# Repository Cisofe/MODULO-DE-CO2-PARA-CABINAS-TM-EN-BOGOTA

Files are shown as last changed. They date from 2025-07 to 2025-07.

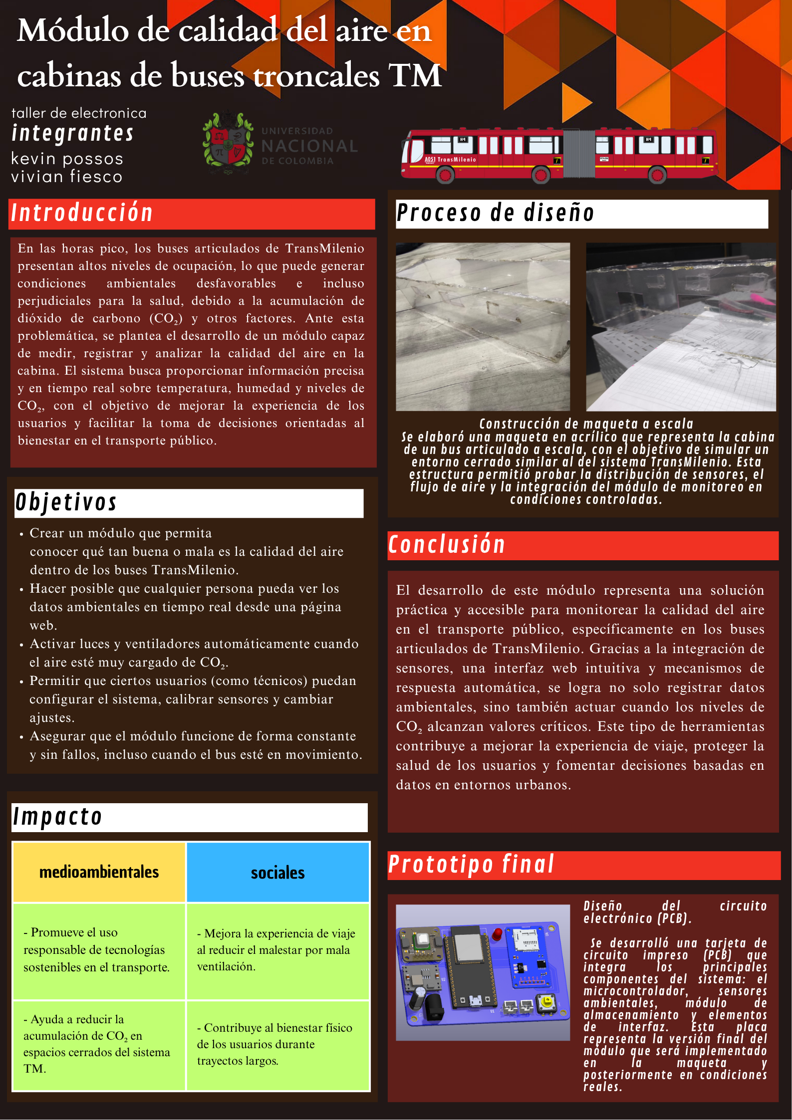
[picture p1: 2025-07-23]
Evidencias/poster.png.png

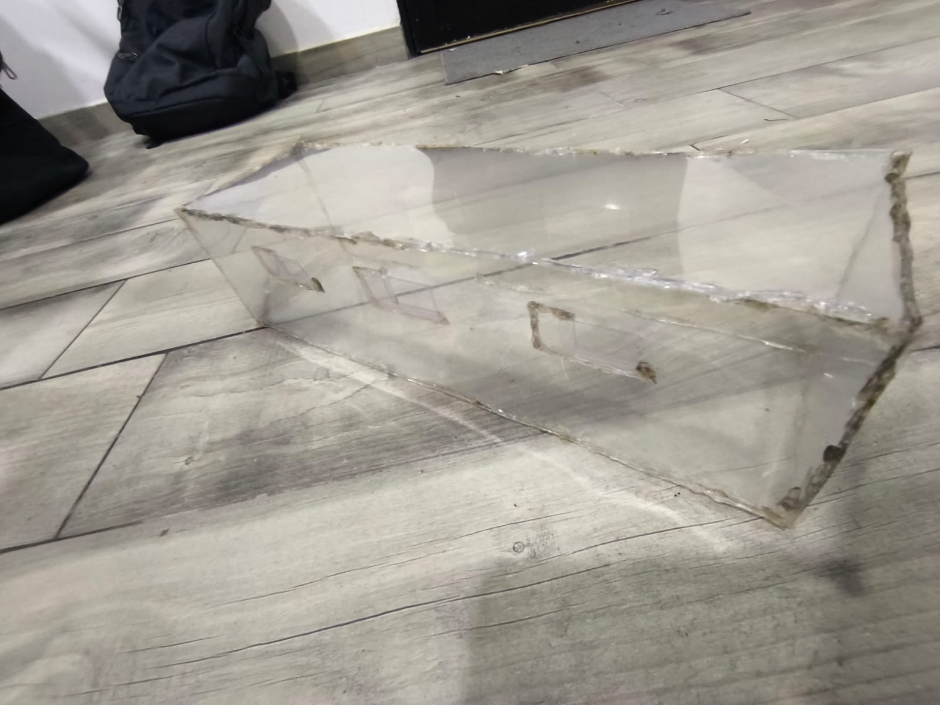
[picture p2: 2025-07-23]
Evidencias/Evidencia_cabina_escala.jpg

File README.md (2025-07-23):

# MODULO-DE-CO2-PARA-CABINAS-TM-EN-BOGOTA
## Proyecto de ingeniería

El módulo de CO2 para buses TM es un prototipo ideado para proporcionar datos para análisis y control de la calidad del aire en las cabinas de buses troncales del sistema BRT de la ciudad de Bogotá, Colombia. El dispositivo permite que los estadísticos y analistas de datos obtengan información de la temperatura, humedad y concentración de CO2 en el interior de los vehículos, además de automatizar el funcionamiento del sistema de ventilación de acuerdo a los valores de concentración de CO2. Las personas que conmutan a diario en los buses también podrán acceder a datos recientes de la calidad del aire en su cabina, lo que busca proporcionar más transparencia y aumentar el interés de los usuarios en el tema. Asimismo, esto podría incidir en el incremento de estudios sobre la aglomeración de TransMilenio y las condiciones del aire en sistemas de transporte masivo público y cómo influyen en el pasajero.

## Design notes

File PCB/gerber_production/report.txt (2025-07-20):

Plotted to 'C:\Users\vivi_\Módulo de CO2 de buses TM\Modulo CO2 de bus TM\gerber_production\Modulo CO2 de bus TM-F_Cu.gbr'.
Plotted to 'C:\Users\vivi_\Módulo de CO2 de buses TM\Modulo CO2 de bus TM\gerber_production\Modulo CO2 de bus TM-B_Cu.gbr'.
Plotted to 'C:\Users\vivi_\Módulo de CO2 de buses TM\Modulo CO2 de bus TM\gerber_production\Modulo CO2 de bus TM-B_Paste.gbr'.
Plotted to 'C:\Users\vivi_\Módulo de CO2 de buses TM\Modulo CO2 de bus TM\gerber_production\Modulo CO2 de bus TM-F_Silkscreen.gbr'.
Plotted to 'C:\Users\vivi_\Módulo de CO2 de buses TM\Modulo CO2 de bus TM\gerber_production\Modulo CO2 de bus TM-B_Silkscreen.gbr'.
Plotted to 'C:\Users\vivi_\Módulo de CO2 de buses TM\Modulo CO2 de bus TM\gerber_production\Modulo CO2 de bus TM-F_Mask.gbr'.
Plotted to 'C:\Users\vivi_\Módulo de CO2 de buses TM\Modulo CO2 de bus TM\gerber_production\Modulo CO2 de bus TM-B_Mask.gbr'.
Plotted to 'C:\Users\vivi_\Módulo de CO2 de buses TM\Modulo CO2 de bus TM\gerber_production\Modulo CO2 de bus TM-Edge_Cuts.gbr'.
Created Gerber job file 'C:\Users\vivi_\Módulo de CO2 de buses TM\Modulo CO2 de bus TM\gerber_production\Modulo CO2 de bus TM-job.gbrjob'.
Info: Done.

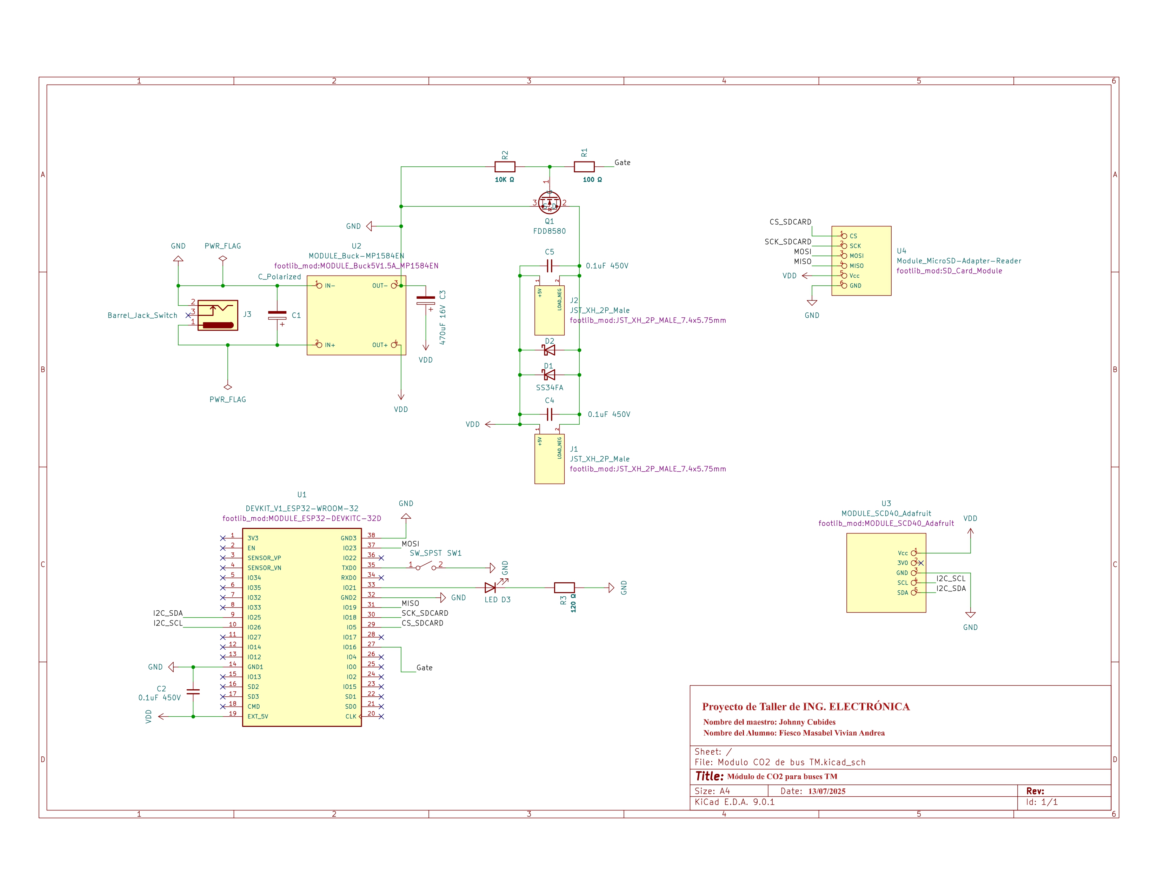
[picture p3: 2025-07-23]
PCB/Schematic_Modulo_CO2_de_bus_TM.jpg

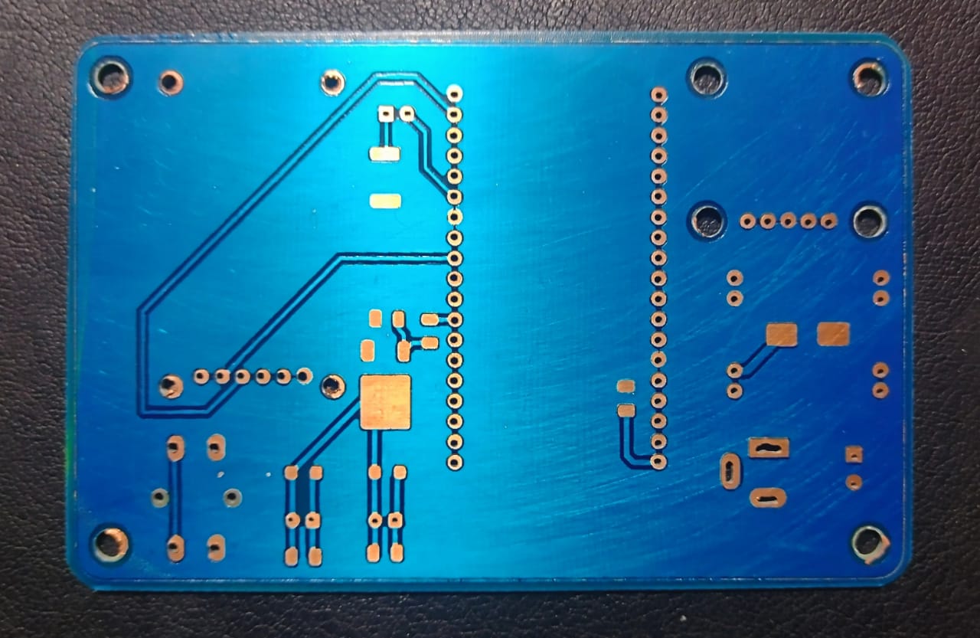
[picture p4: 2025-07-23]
Evidencias/pcb_layout_Back.jpeg

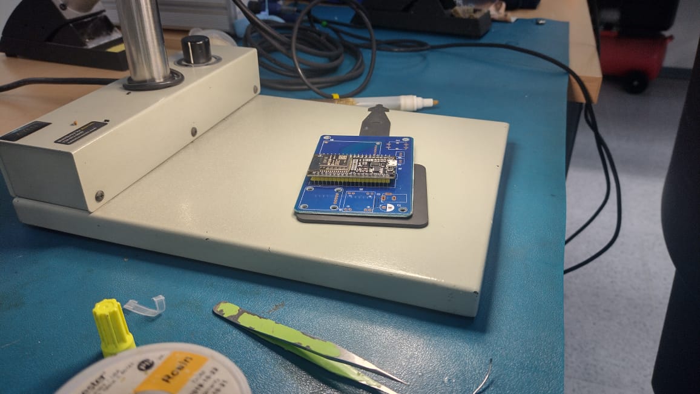
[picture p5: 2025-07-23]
Evidencias/Evidencia_soldadura1.jpeg

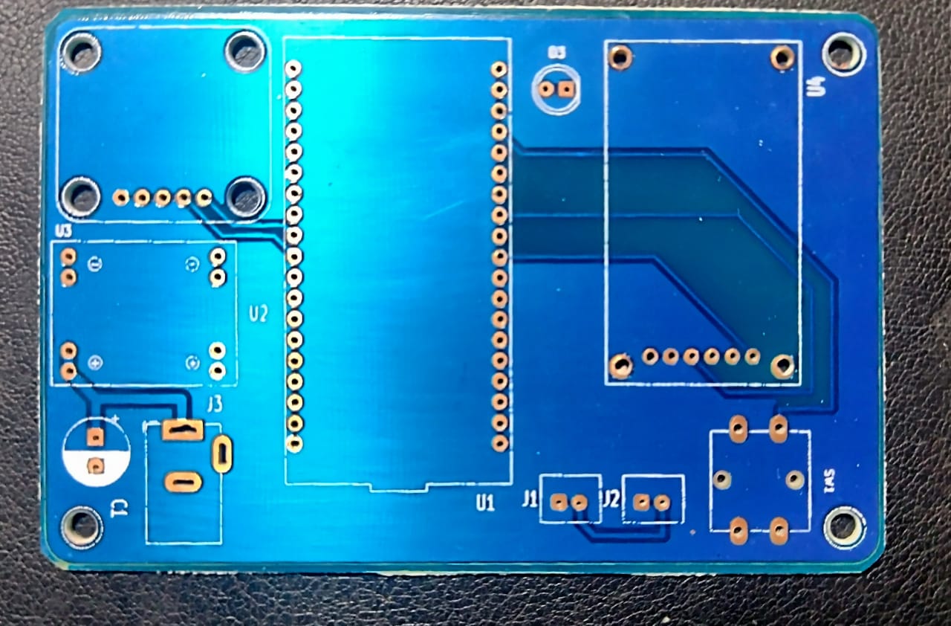
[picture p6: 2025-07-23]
Evidencias/pcb_layout_Front.jpeg

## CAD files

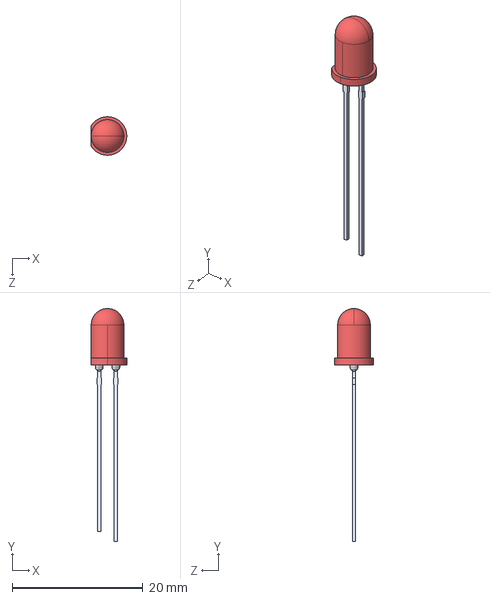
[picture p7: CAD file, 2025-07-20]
PCB/3d-models/LED_5mm.STEP
5.45 x 35.6 x 5.90 mm

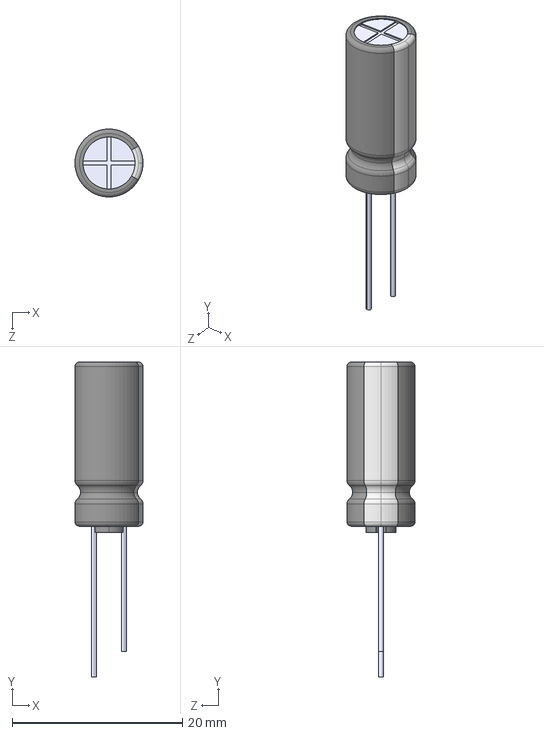
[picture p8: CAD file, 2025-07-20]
PCB/3d-models/CAP_8mm 3.5mm.STEP
8.00 x 37.0 x 7.99 mm

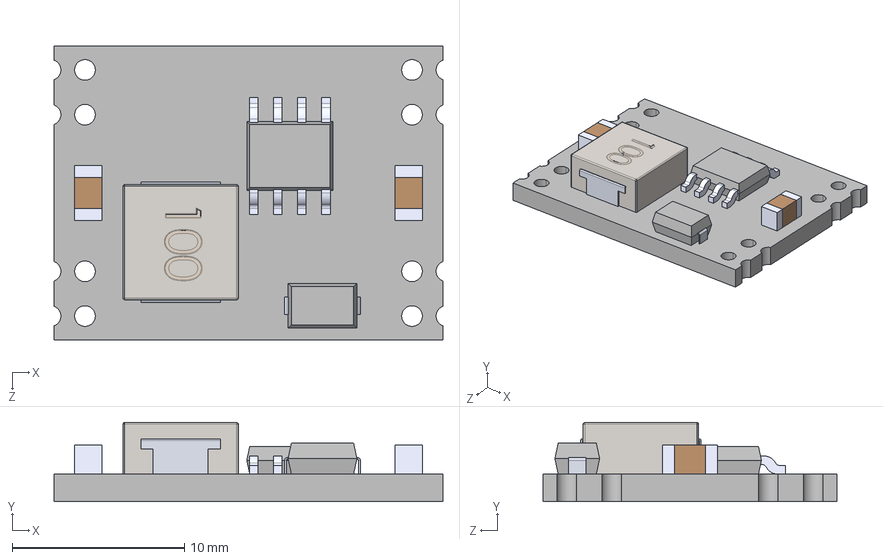
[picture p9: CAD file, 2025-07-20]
PCB/3d-models/DC-DC 5V-12V To 3.3V Step Down Voltage Regulator Power Module Board.STEP
22.6 x 4.60 x 17.1 mm
PCB, DC-DC 5V-12V To 3.3V Step Down Voltage Regulator Power Module Board
IC Chip, DC-DC 5V-12V To 3.3V Step Down Voltage Regulator Power Module Board
Inductor, DC-DC 5V-12V To 3.3V Step Down Voltage Regulator Power Module Board
Schottky Diode, DC-DC 5V-12V To 3.3V Step Down Voltage Regulator Power Module Board
SMD Resistor, DC-DC 5V-12V To 3.3V Step Down Voltage Regulator Power Module Board x 2

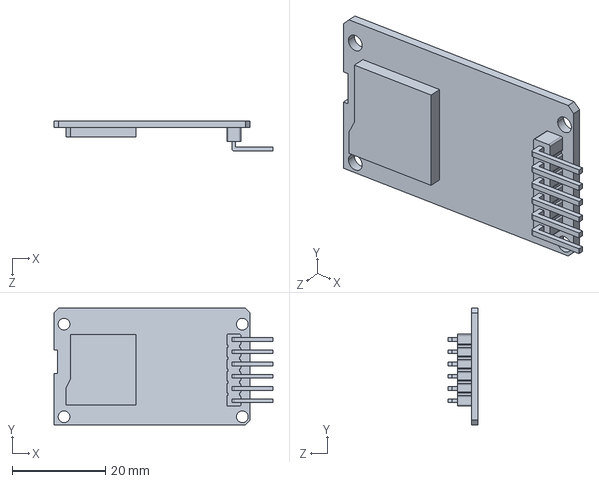
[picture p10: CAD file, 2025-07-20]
PCB/3d-models/sdreader.STEP
46.9 x 25.0 x 6.40 mm

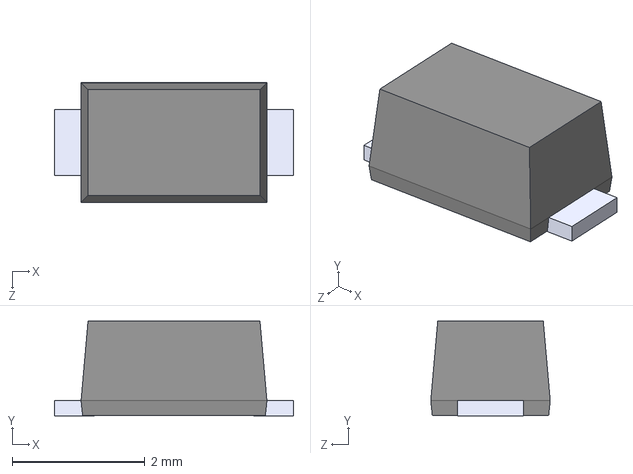
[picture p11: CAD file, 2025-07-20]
PCB/3d-models/SS34FA--3DModel-STEP-510211.STEP
3.60 x 1.43 x 1.80 mm

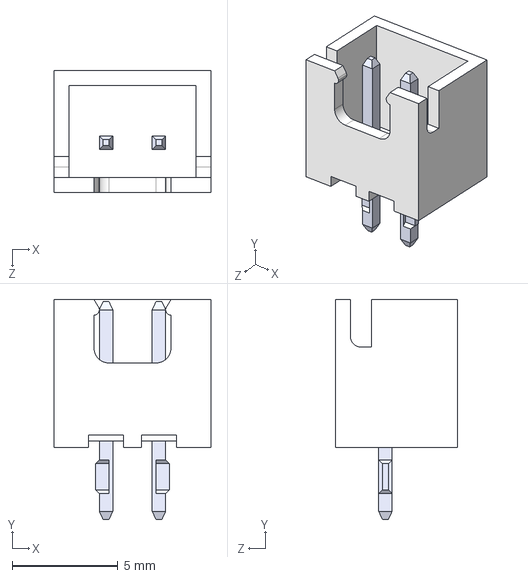
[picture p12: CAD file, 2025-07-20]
PCB/3d-models/B2B-XH-A-LF--SN---3DModel-STEP-269445.STEP
7.40 x 10.4 x 5.75 mm

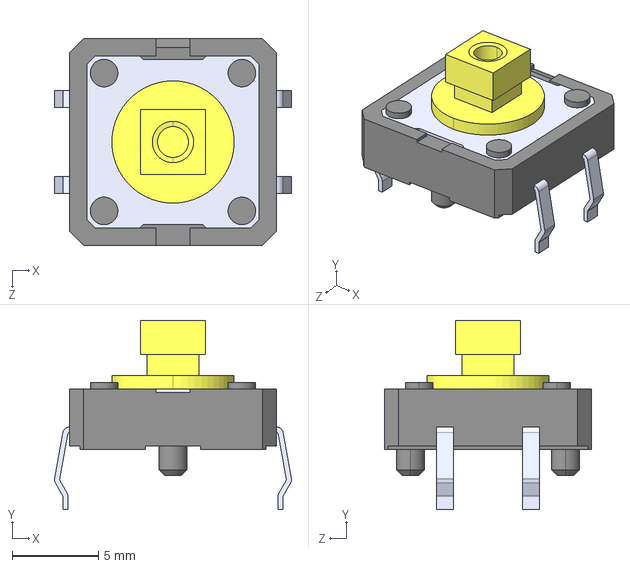
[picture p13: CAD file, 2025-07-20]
PCB/3d-models/B3F-4055--3DModel-STEP-418109.STEP
13.8 x 11.0 x 12.0 mm

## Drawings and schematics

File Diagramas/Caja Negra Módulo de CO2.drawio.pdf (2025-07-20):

## Aire

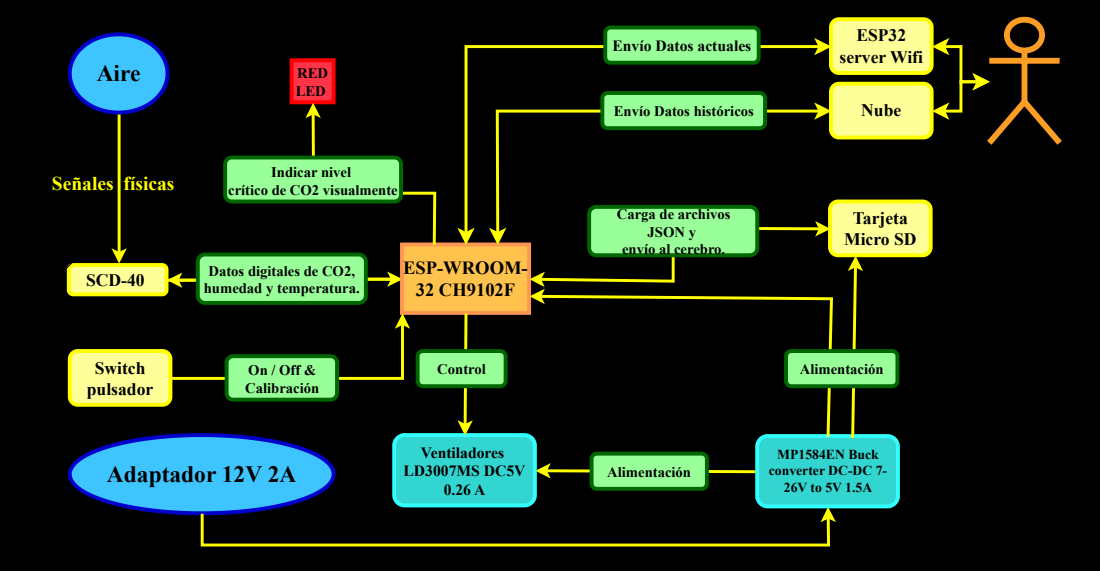
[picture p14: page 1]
SCD-40; Señales; físicas; ESP-WROOM- 32 CH9102F; Adaptador 12V 2A; Tarjeta Micro SD; Actor; Nube; ESP32 server Wifi; Alimentación; Ventiladores LD3007MS DC5V 0.26 A; Control; RED LED; Switch pulsador; On / Off & Calibración

Envío Datos actuales

Envío Datos históricos

Indicar nivel
crítico de CO2 visualmente

Carga de archivos
JSON y
envío al cerebro.

Datos digitales de CO2,
humedad y temperatura.

MP1584EN Buck
converter DC-DC 7-

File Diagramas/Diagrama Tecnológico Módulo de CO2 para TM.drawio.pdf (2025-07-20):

## Aire

## Señales físicas

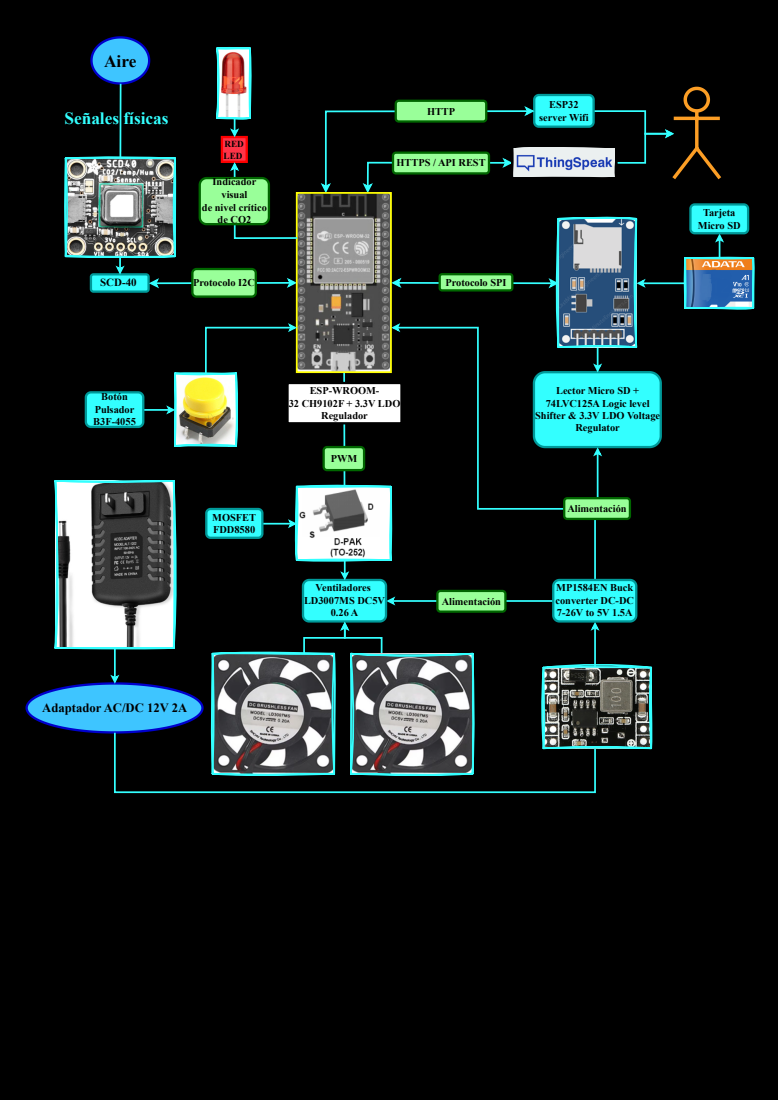
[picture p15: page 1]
SCD-40; Regulator; Actor; ESP32 server Wifi; Alimentación; HTTP; Ventiladores LD3007MS DC5V 0.26 A; MOSFET FDD8580; RED LED; Protocolo I2C; ESP-WROOM- 32 CH9102F + 3.3V LDO Regulador; Protocolo SPI; Tarjeta Micro SD; Botón Pulsador B3F-4055; PWM

HTTPS / API REST

Indicador
visual
de nivel crítico

Lector Micro SD +
74LVC125A Logic level
Shifter & 3.3V LDO Voltage

MP1584EN Buck
converter DC-DC

Adaptador AC/DC 12V 2A

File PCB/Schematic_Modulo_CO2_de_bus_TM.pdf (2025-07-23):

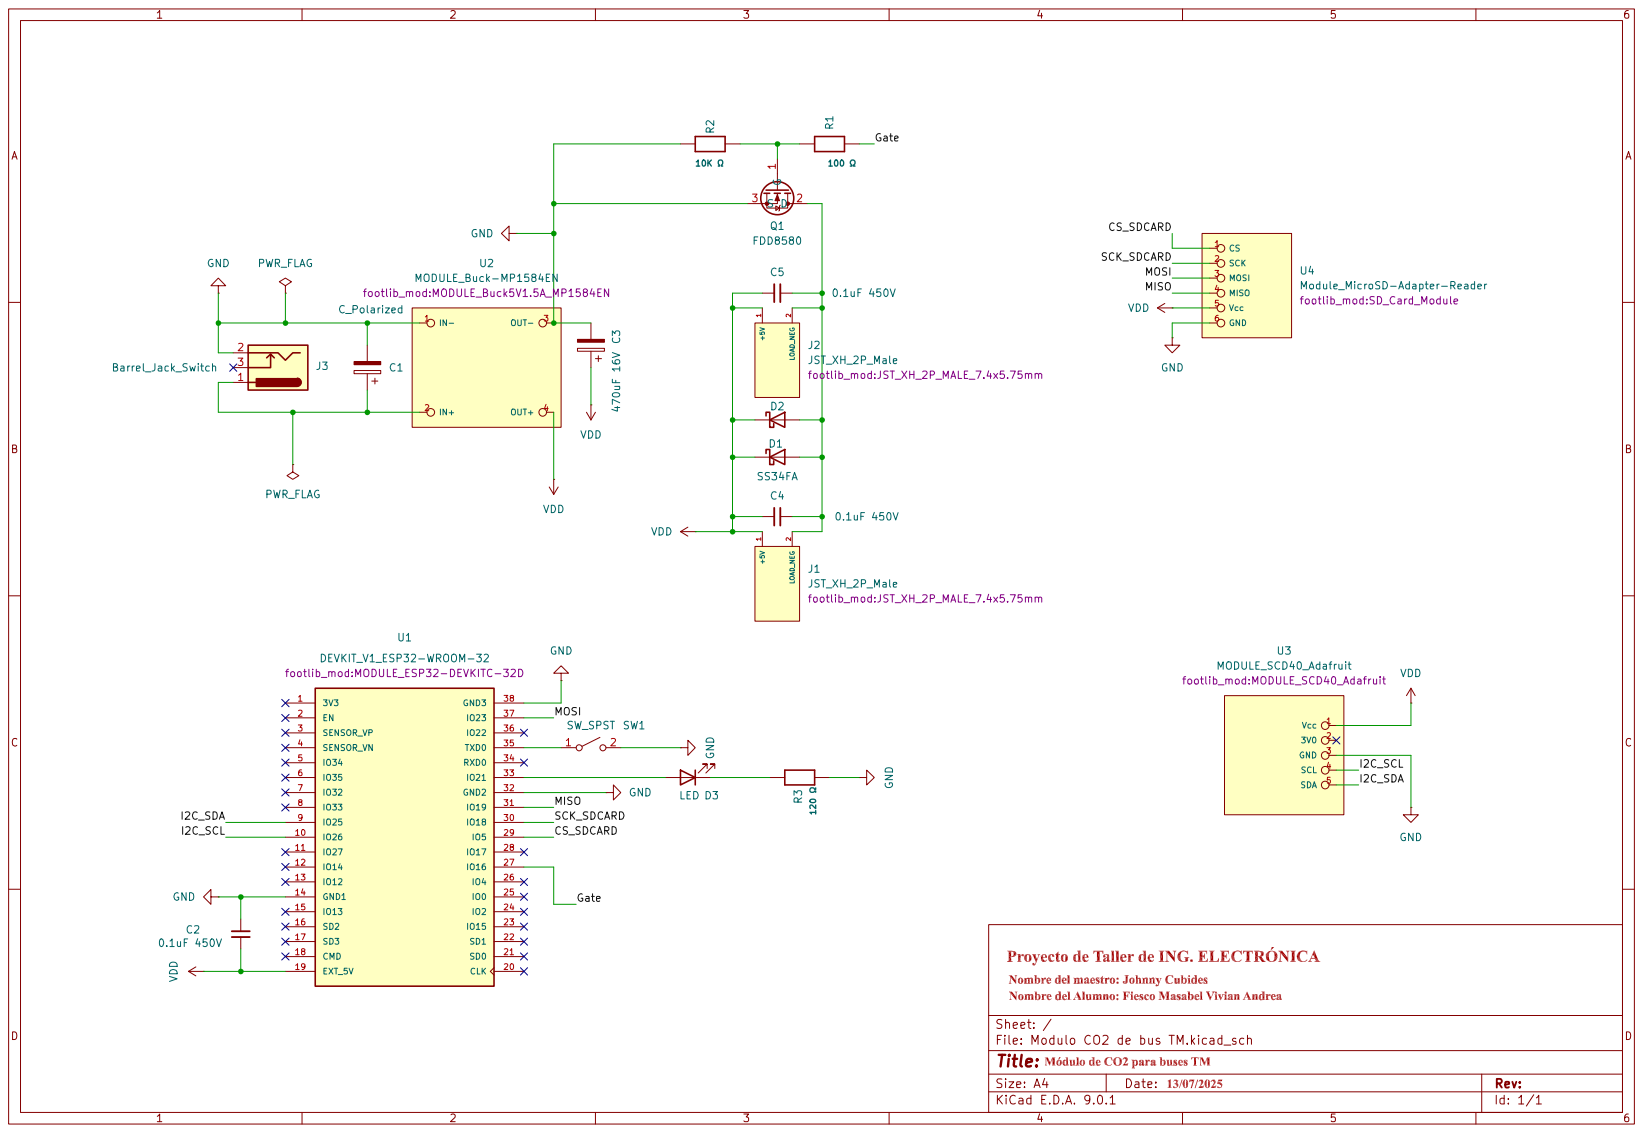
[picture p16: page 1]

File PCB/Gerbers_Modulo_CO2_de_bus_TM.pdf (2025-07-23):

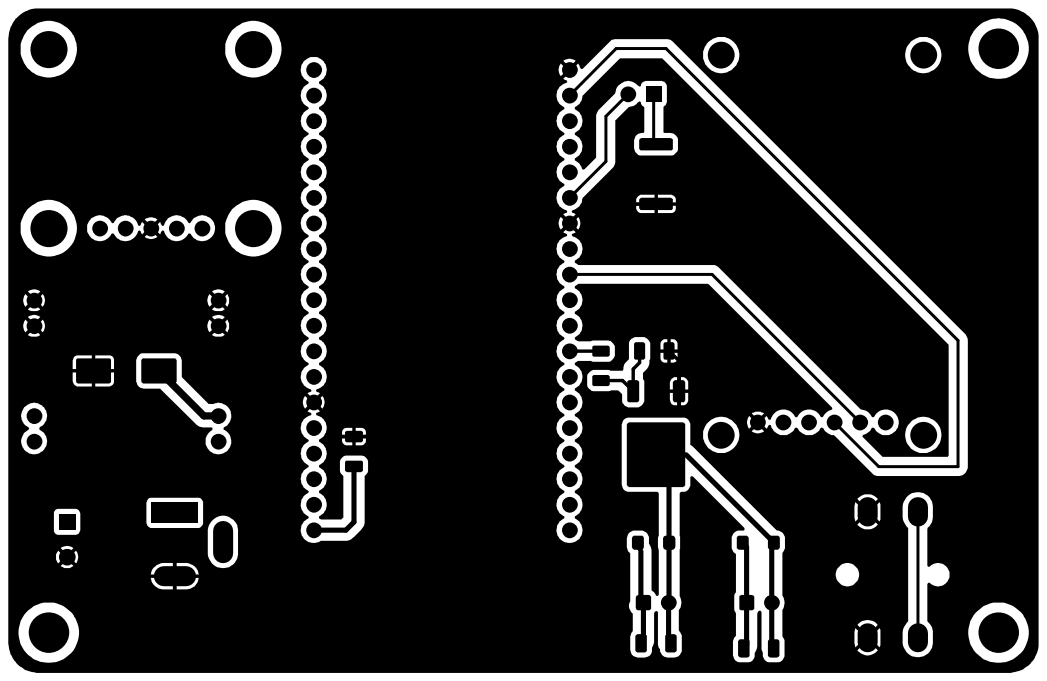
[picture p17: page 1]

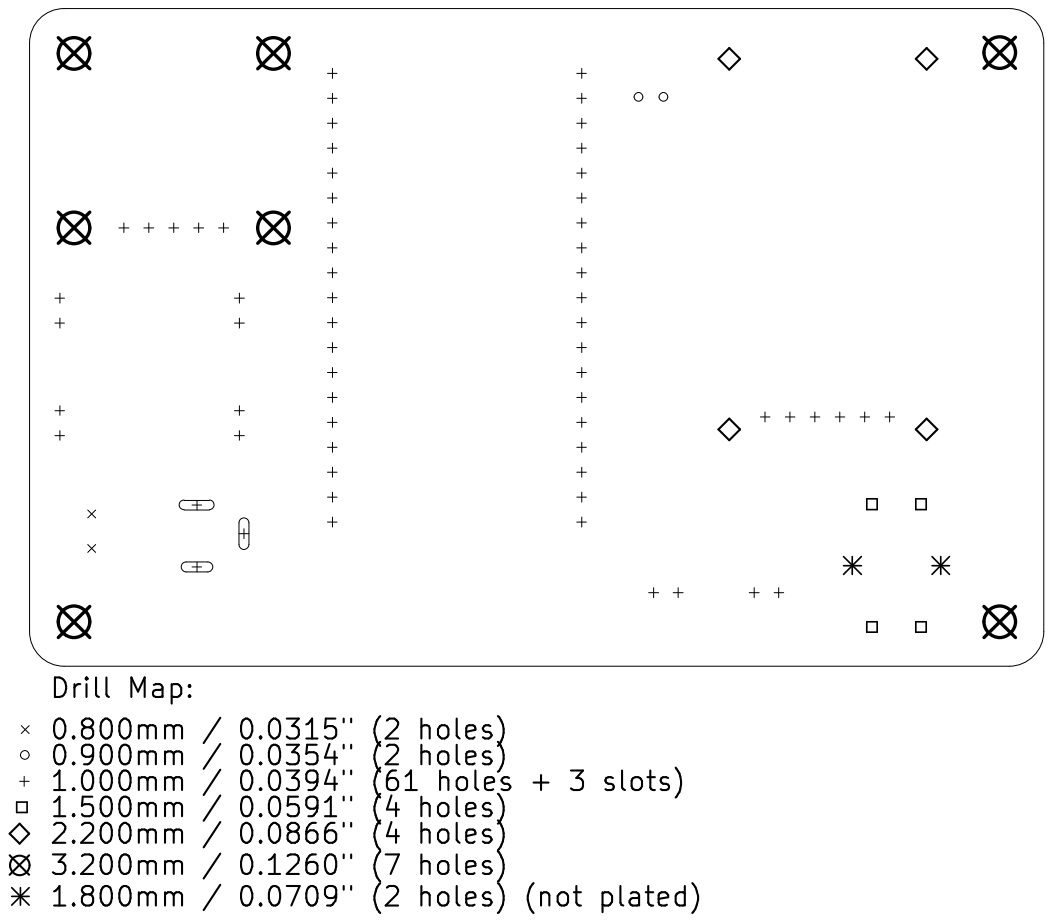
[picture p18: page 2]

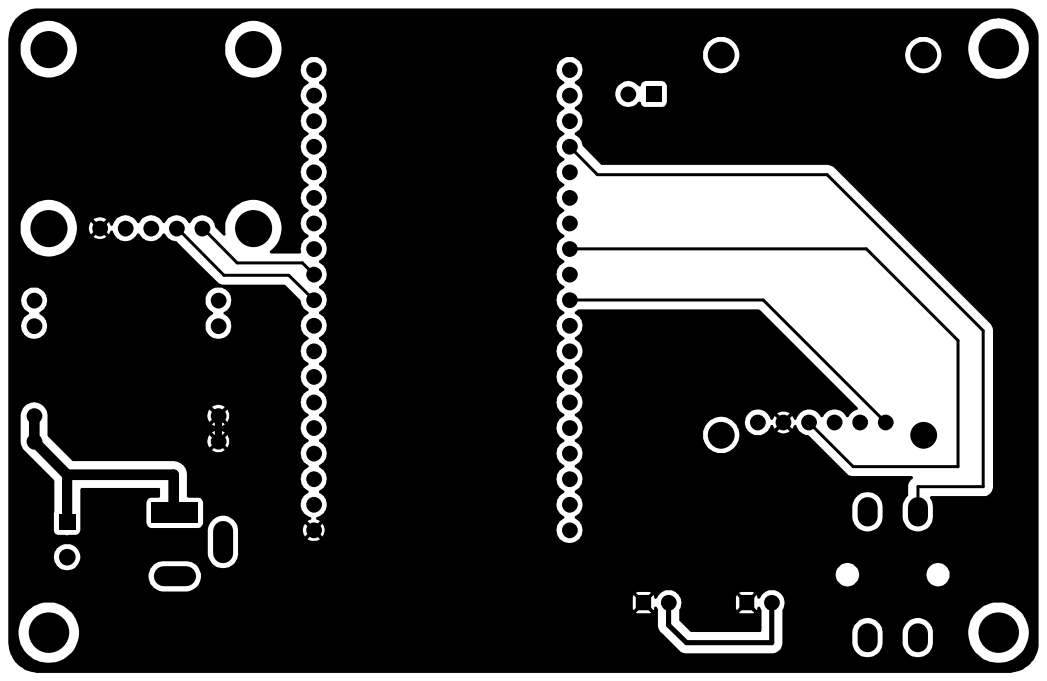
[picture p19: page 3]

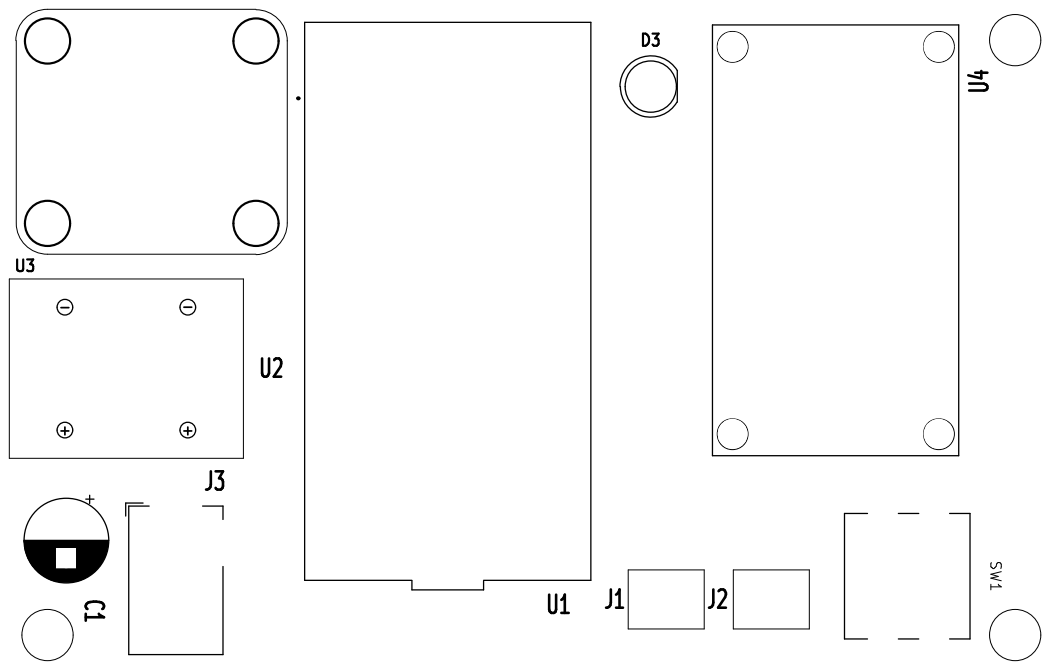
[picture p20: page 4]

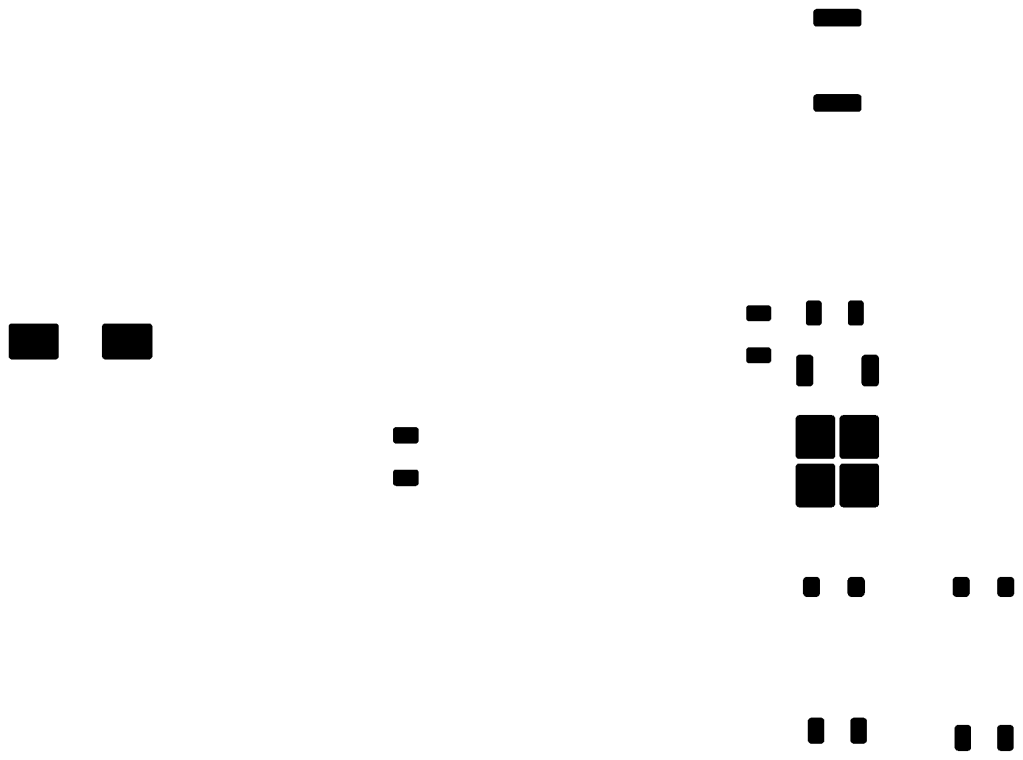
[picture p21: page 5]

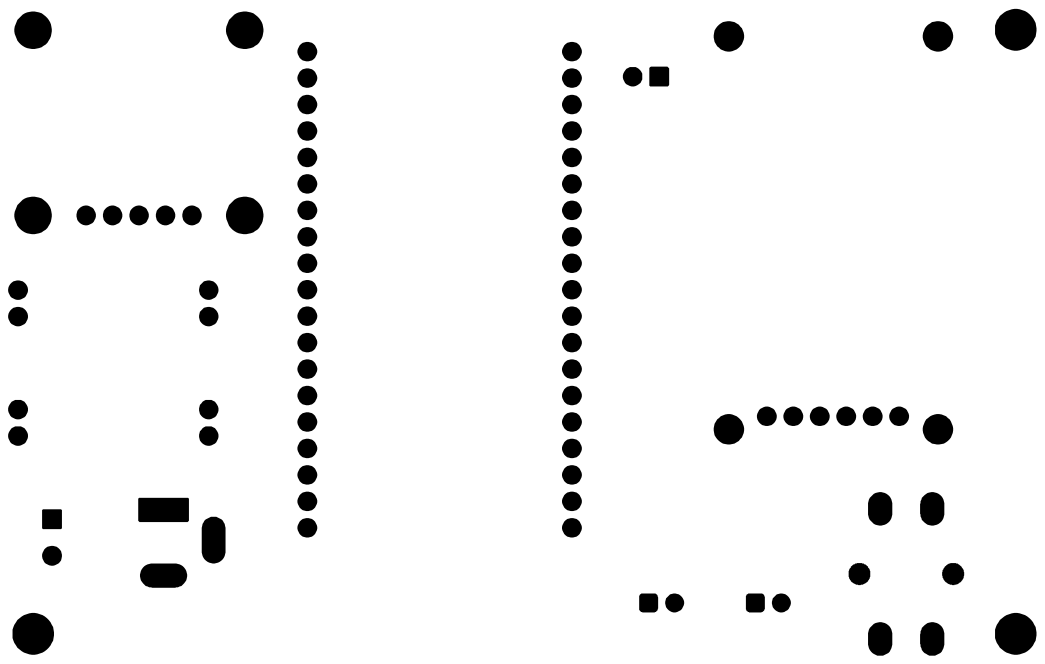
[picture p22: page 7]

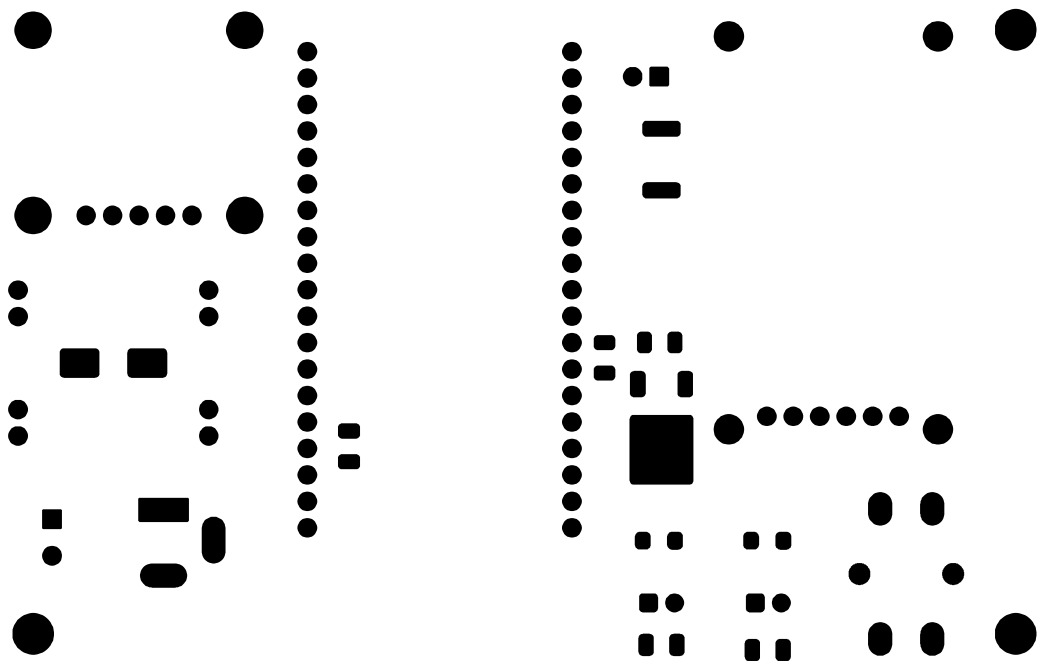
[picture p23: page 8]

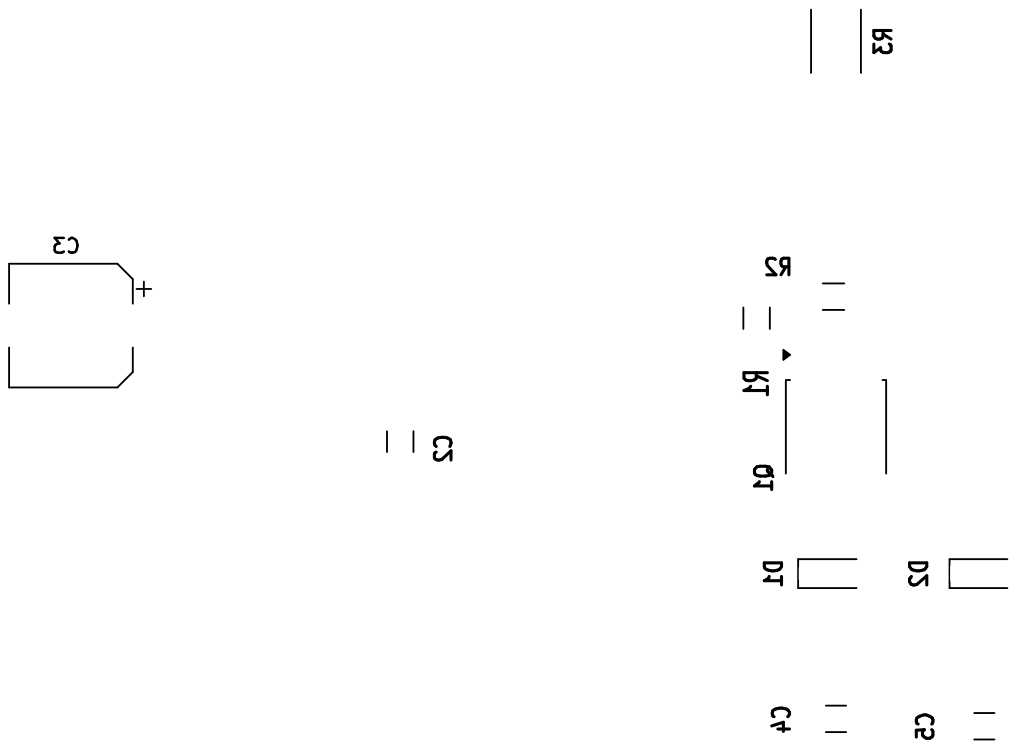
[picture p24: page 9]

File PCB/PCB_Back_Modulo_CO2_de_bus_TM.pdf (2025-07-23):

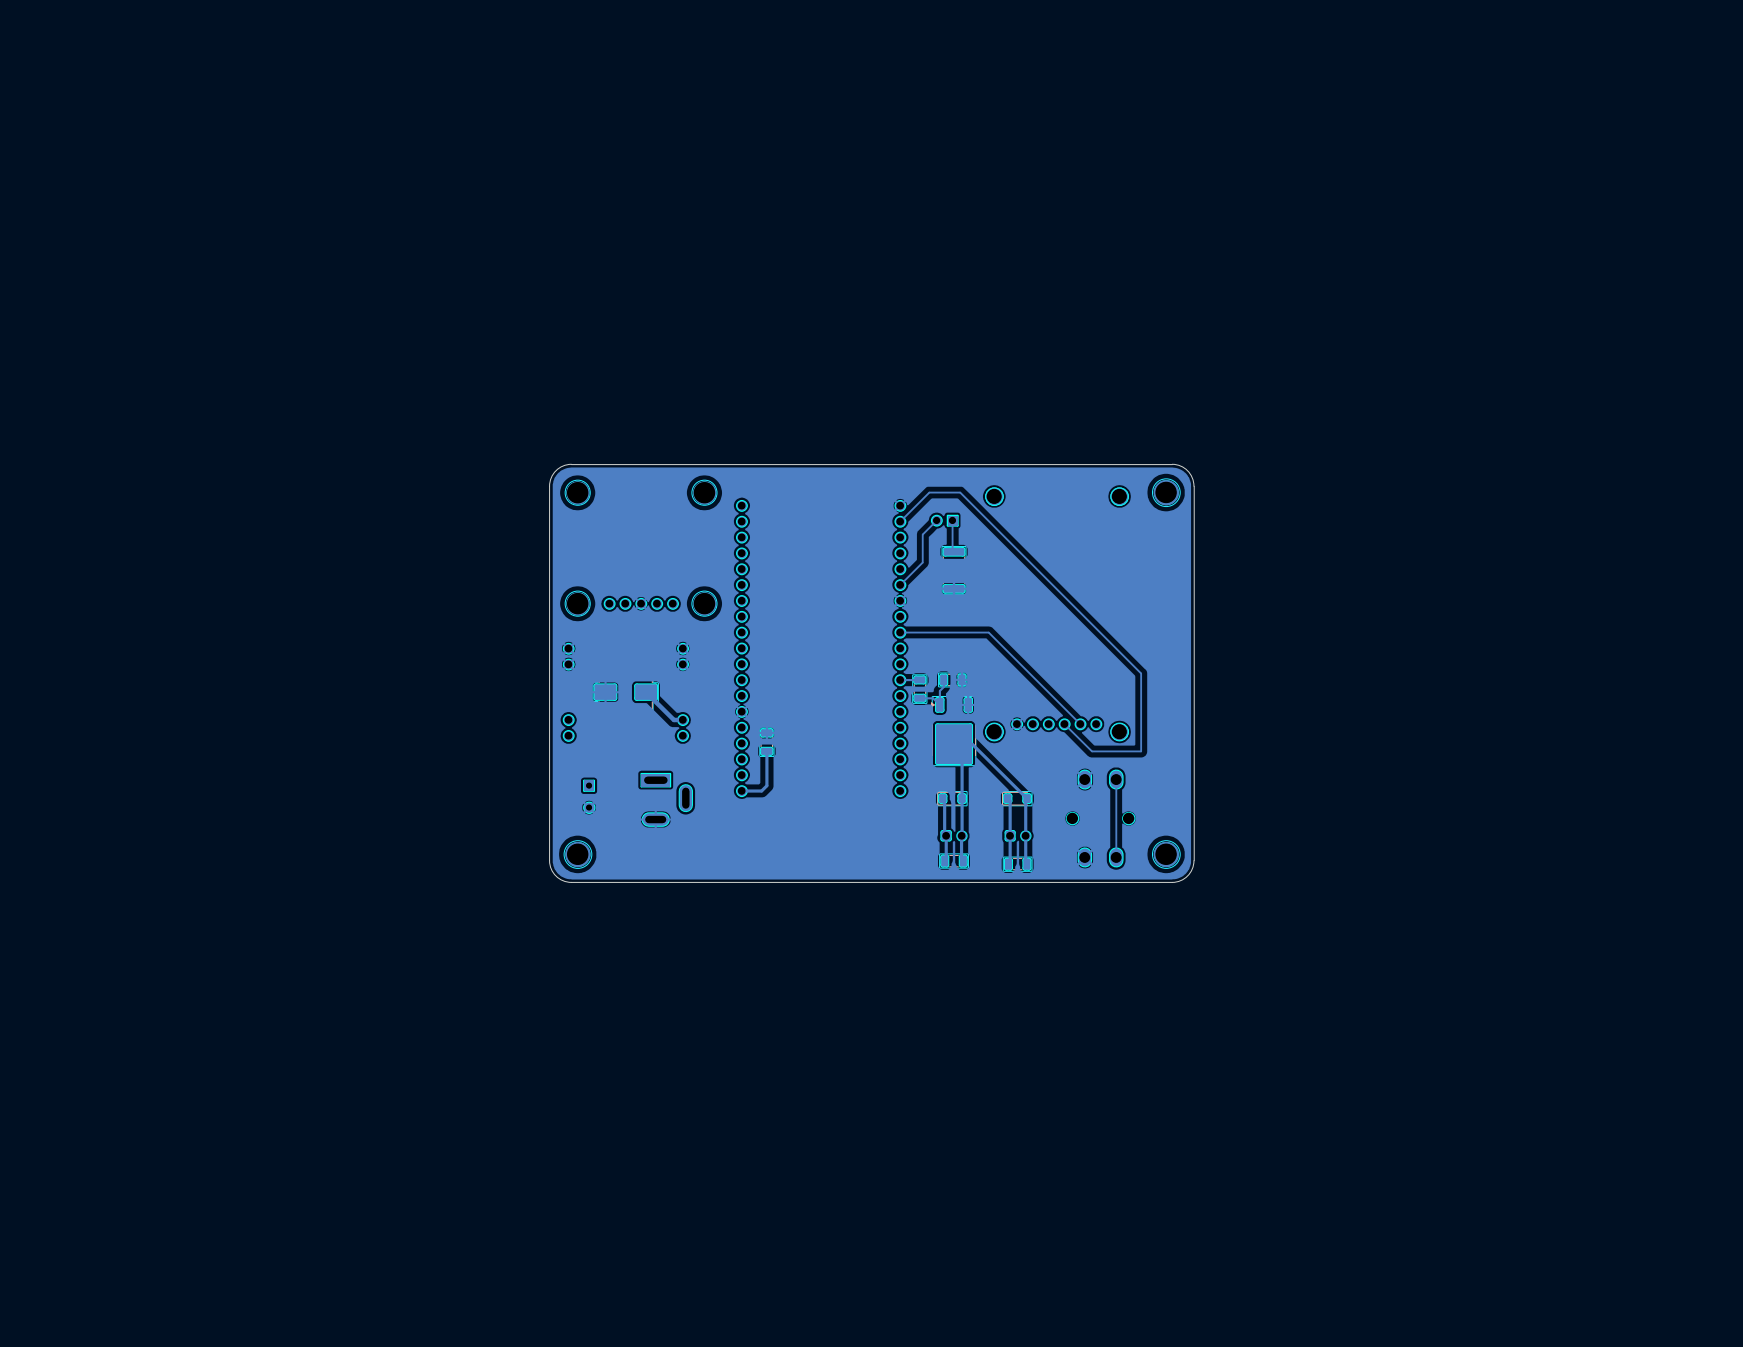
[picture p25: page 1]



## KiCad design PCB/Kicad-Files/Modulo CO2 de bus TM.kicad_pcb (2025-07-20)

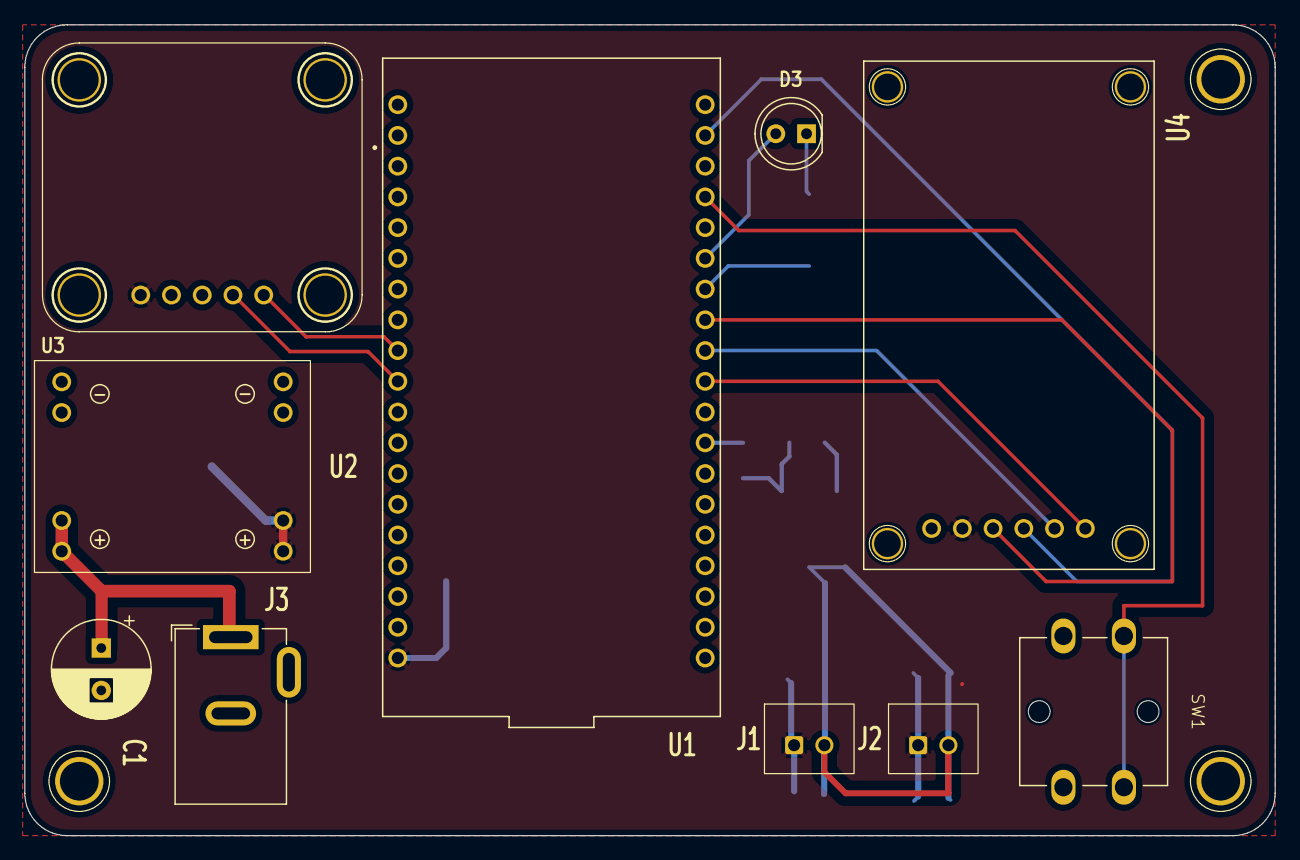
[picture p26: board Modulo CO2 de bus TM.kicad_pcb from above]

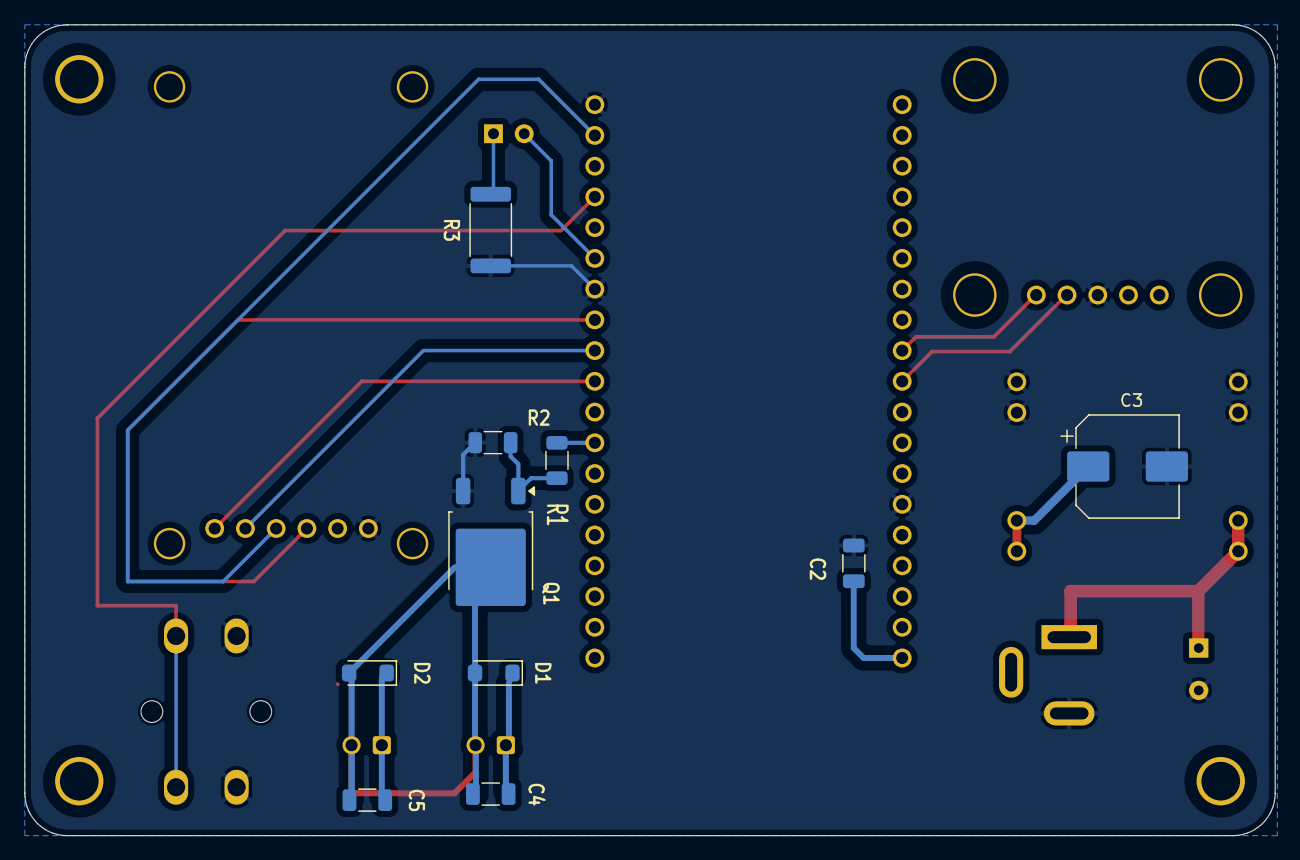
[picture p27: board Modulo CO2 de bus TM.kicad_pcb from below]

Board: 2 copper layers, 103.3 x 67.0 mm, 20 parts (10 on the bottom side), 15 nets.

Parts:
C1: C_Polarized; Cap_Elec_THT_8 mm 3,50 mm
C2, C4, C5: 0.1uF 450V; C_1206_3216Metric
C3: 470uF 16V; CP_Elec_8x10
D1: SS34FA; D_SOD-123FA
D2: SS34; D_SOD-123FA
D3: LED; LED_5.0mm
J1, J2: JST_XH_2P_Male; JST_XH_2P_MALE_7.4x5.75mm
J3: Barrel_Jack_Switch; BarrelJack_Sw
Q1: FDD8580; TO-252-2
R1: 100 Ω; R_1206_3216Metric
R2: 10K Ω; R_1206_3216Metric
R3: 120 Ω; R_2512_6332Metric
SW1: SW_SPST; B3F-4055 12x12x7,3
U1: DEVKIT_V1_ESP32-WROOM-32; MODULE_ESP32-DEVKITC-32D
U2: MODULE_Buck-MP1584EN; MODULE_Buck5V1.5A_MP1584EN
U3: MODULE_SCD40_Adafruit
U4: Module_MicroSD-Adapter-Reader; SD_Card_Module

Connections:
/CS_SDCARD: U1.29 (IO5), U4.1 (CS)
/Gate: R1.2, U1.27 (IO16)
/I2C_SCL: U1.10 (IO26), U3.4 (SCL)
/I2C_SDA: U1.9 (IO25), U3.5 (SDA)
/MISO: U1.31 (IO19), U4.4 (MISO)
/MOSI: U1.37 (IO23), U4.3 (MOSI)
/SCK_SDCARD: U1.30 (IO18), U4.2 (SCK)
GND: C1.2, C2.2, C3.2, J3.2, Q1.3 (S), R2.1, R3.1, SW1.2 (B), U1.14 (GND1), U1.32 (GND2), U1.38 (GND3), U2.1 (IN-), U2.3 (OUT-), U3.3 (GND), U4.6 (GND)
unnamed: C4.1, C5.1, D1.2 (A), D2.2 (A), J1.2 (LOAD_NEG), J2.2 (LOAD_NEG), Q1.2 (D)
unnamed: D3.2 (A), U1.33 (IO21)
unnamed: D3.1 (K), R3.2
unnamed: Q1.1 (G), R1.1, R2.2
unnamed: SW1.1 (A), U1.35 (TXD0)
unnamed: C1.1, J3.1, U2.2 (IN+)
VDD: C2.1, C3.1, C4.2, C5.2, D1.1 (K), D2.1 (K), J1.1 (+5V), J2.1 (+5V), U1.19 (EXT_5V), U2.4 (OUT+), U3.1 (Vcc), U4.5 (Vcc)
